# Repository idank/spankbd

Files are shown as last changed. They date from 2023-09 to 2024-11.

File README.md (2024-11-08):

# Span keyboard

span

Span is a low profile split keyboard with 3x5 column staggered keys with 2u, 1.5u, 1u thumb clusters.

The keyboard layout is derived from GergoPlex, a keyboard that was originally available on gboards.ca
(now defunct).

Features:

* 18x17 mm choc spacing.
* Optional 2u choc stabilizer.
* OLED support.
* Hybrid hotswap / direct soldering for switches.

The pcbs aren't reversible at the moment: I prefer the cleaner look of the top
side and generally think it's easier to deal with. A reversible version may be
added in the future.

## Availability

Kits and built keyboards can be purchased on *[holykeebs](https://holykeebs.com)*.

Gerber files are available in the releases page.

span bottom plate
span with an oled

## Guide

See this [page](https://docs.holykeebs.com/guides/keyboard/).

## License

This work is licensed under a
[Creative Commons Attribution-ShareAlike 4.0 International License][cc-by-sa].

[cc-by-sa]: http://creativecommons.org/licenses/by-sa/4.0/

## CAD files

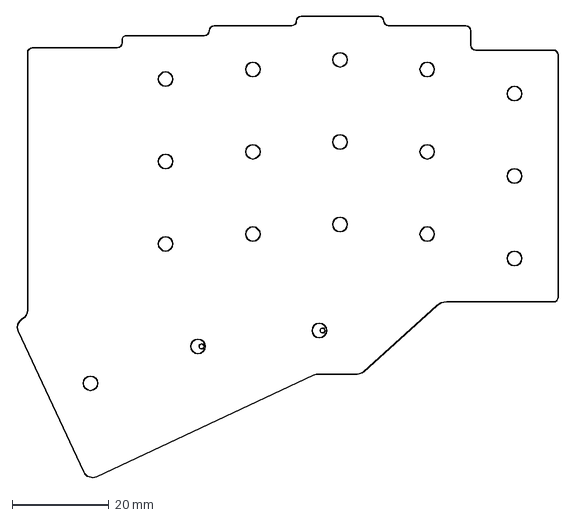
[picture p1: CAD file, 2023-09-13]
pcb/outline.dxf
111.9 x 95.3 mm

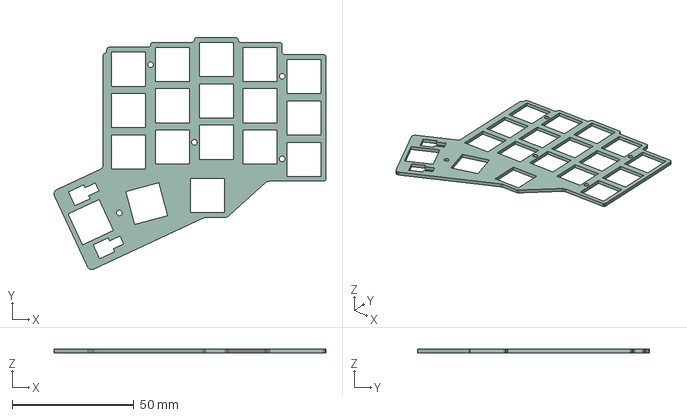
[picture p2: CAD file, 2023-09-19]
plate/span.step
111.6 x 95.2 x 1.58 mm

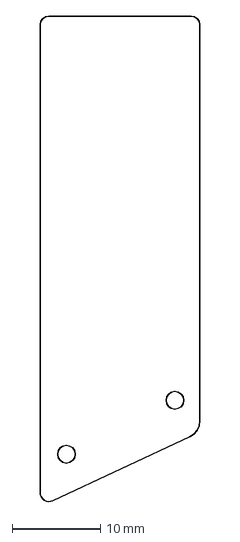
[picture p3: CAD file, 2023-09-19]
misc/oled.dxf
18.1 x 55.0 mm

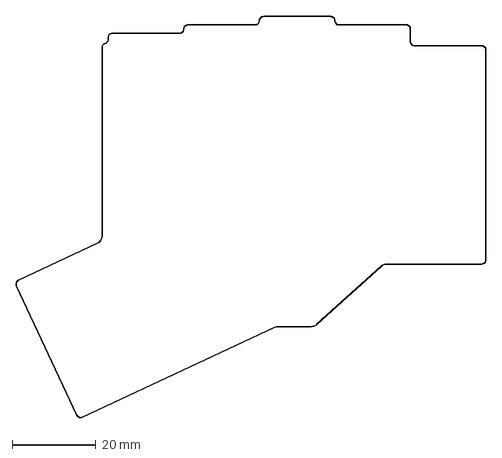
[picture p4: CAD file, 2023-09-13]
plate/plate.dxf
112.0 x 95.6 mm

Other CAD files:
misc/acrylic plate.dxf
plate/span plate.STEP

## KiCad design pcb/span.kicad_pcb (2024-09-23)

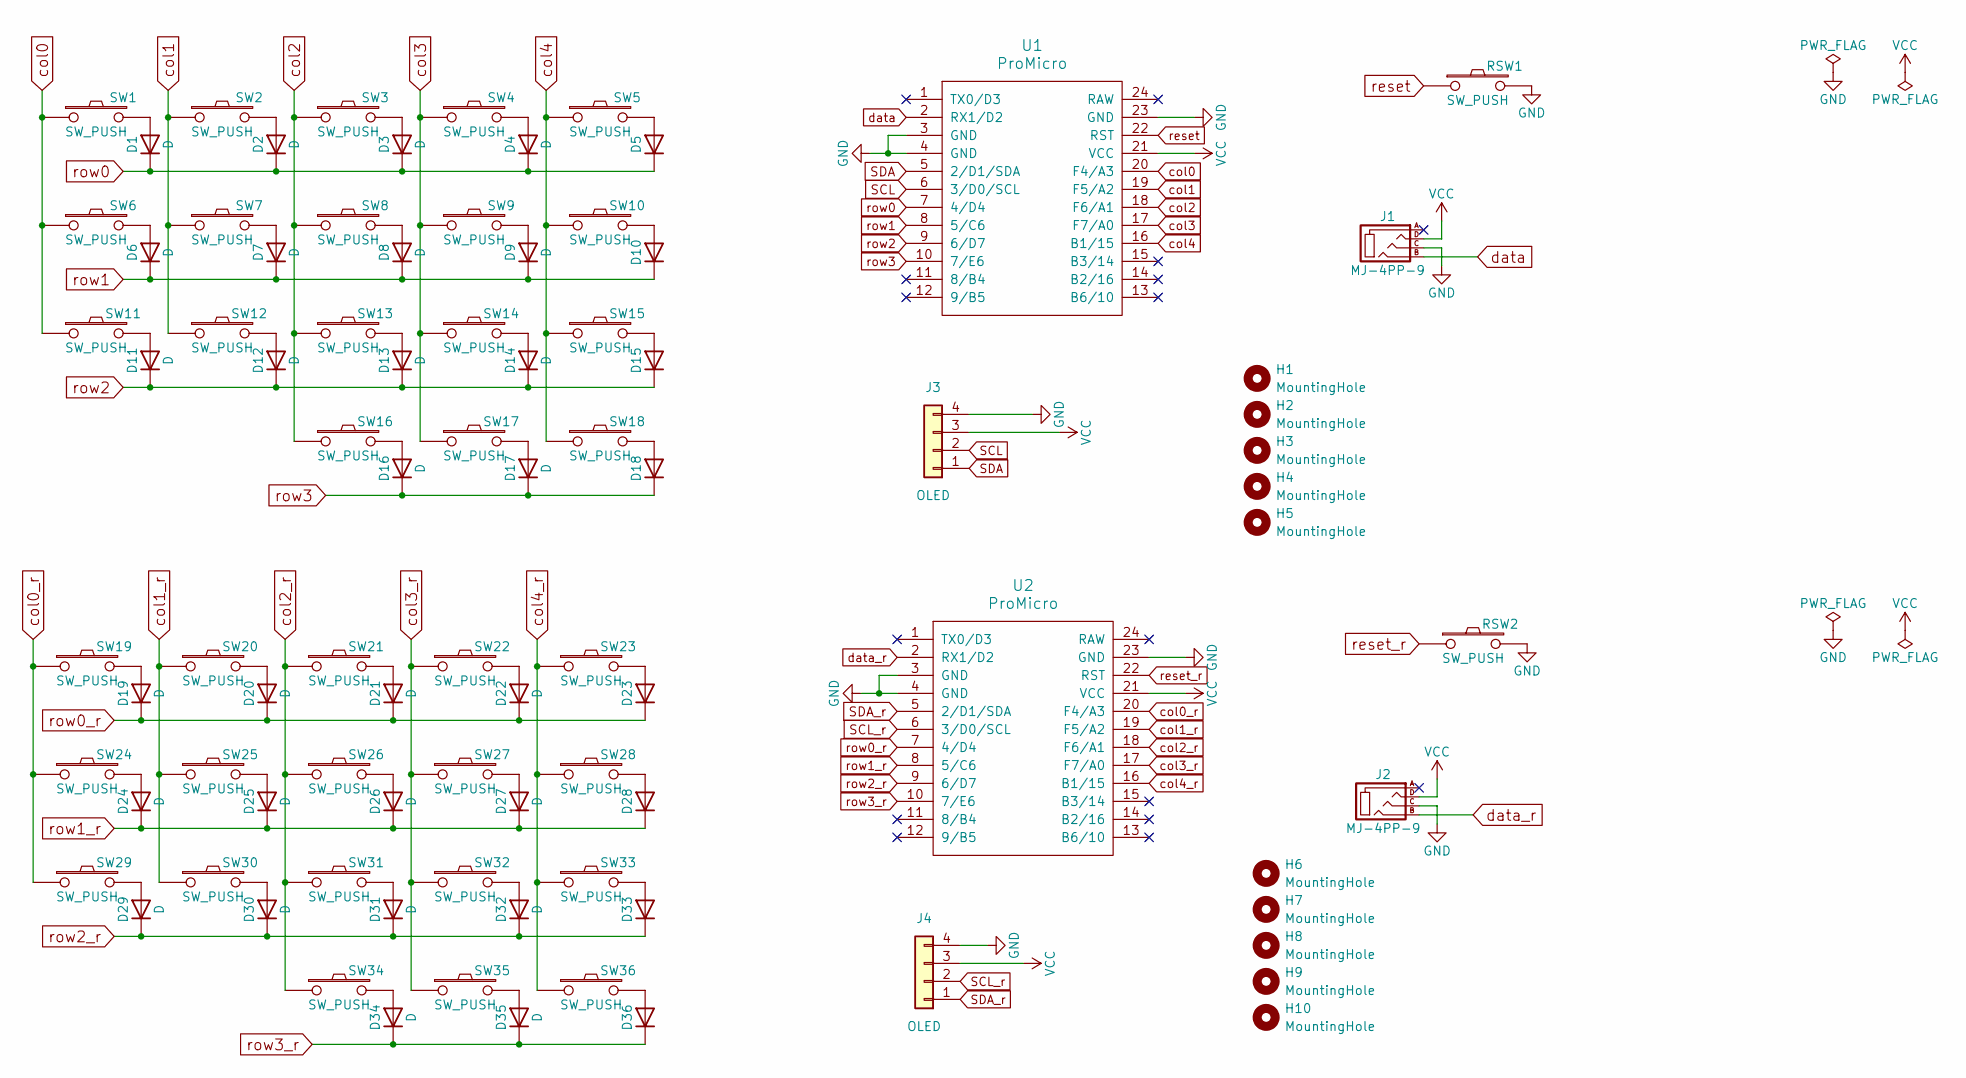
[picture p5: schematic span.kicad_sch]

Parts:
D1, D2, D3, D4, D5, D6, D7, D8, D9, D10, D11, D12, D13, D14, D15, D16, D17, D18, D19, D20, D21, D22, D23, D24, D25, D26, D27, D28, D29, D30, D31, D32, D33, D34, D35, D36: D; D3_SMD_v2
H1, H2, H3, H4, H5, H6, H7, H8, H9, H10: MountingHole; M2_SPACER
J1, J2: MJ-4PP-9; MJ-4PP-9_1side
J3, J4: OLED; OLED_1side
RSW1, RSW2: SW_PUSH; RSW_2PIN_SMD
SW1, SW2, SW3, SW4, SW5, SW6, SW7, SW8, SW9, SW10, SW11, SW12, SW13, SW14, SW15, SW16, SW17, SW19, SW20, SW21, SW22, SW23, SW24, SW25, SW26, SW27, SW28, SW29, SW30, SW31, SW32, SW33, SW34, SW35: SW_PUSH; Kailh_socket_PG1350_optional_oval_smaller_hotswap
SW18, SW36: SW_PUSH; Kailh_socket_PG1350_2u_optional_oval
U1, U2: ProMicro; ProMicro_1mm_holes

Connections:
GND: J1.C, J2.C, J3.4, J4.4, RSW1.2, RSW2.2, U1.3 (GND), U1.4 (GND), U1.23 (GND), U2.3 (GND), U2.4 (GND), U2.23 (GND)
unnamed: D1.2 (A), SW1.2
unnamed: D2.2 (A), SW2.2
unnamed: D3.2 (A), SW3.2
unnamed: D4.2 (A), SW4.2
unnamed: D5.2 (A), SW5.2
unnamed: D6.2 (A), SW6.2
unnamed: D7.2 (A), SW7.2
unnamed: D8.2 (A), SW8.2
unnamed: D9.2 (A), SW9.2
unnamed: D10.2 (A), SW10.2
unnamed: D11.2 (A), SW11.2
unnamed: D12.2 (A), SW12.2
unnamed: D13.2 (A), SW13.2
unnamed: D14.2 (A), SW14.2
unnamed: D15.2 (A), SW15.2
unnamed: D16.2 (A), SW16.2
unnamed: D17.2 (A), SW17.2
unnamed: D18.2 (A), SW18.2
unnamed: D19.2 (A), SW19.2
unnamed: D20.2 (A), SW20.2
unnamed: D21.2 (A), SW21.2
unnamed: D22.2 (A), SW22.2
unnamed: D23.2 (A), SW23.2
unnamed: D24.2 (A), SW24.2
unnamed: D25.2 (A), SW25.2
unnamed: D26.2 (A), SW26.2
unnamed: D27.2 (A), SW27.2
unnamed: D28.2 (A), SW28.2
unnamed: D29.2 (A), SW29.2
unnamed: D30.2 (A), SW30.2
unnamed: D31.2 (A), SW31.2
unnamed: D32.2 (A), SW32.2
unnamed: D33.2 (A), SW33.2
unnamed: D34.2 (A), SW34.2
unnamed: D35.2 (A), SW35.2
unnamed: D36.2 (A), SW36.2
SCL: J3.2, U1.6 (3/D0/SCL)
SCL_r: J4.2, U2.6 (3/D0/SCL)
SDA: J3.1, U1.5 (2/D1/SDA)
SDA_r: J4.1, U2.5 (2/D1/SDA)
VCC: J1.D, J2.D, J3.3, J4.3, U1.21 (VCC), U2.21 (VCC)
col0: SW1.1, SW6.1, SW11.1, U1.20 (F4/A3)
col0_r: SW19.1, SW24.1, SW29.1, U2.20 (F4/A3)
col1: SW2.1, SW7.1, SW12.1, U1.19 (F5/A2)
col1_r: SW20.1, SW25.1, SW30.1, U2.19 (F5/A2)
col2: SW3.1, SW8.1, SW13.1, SW16.1, U1.18 (F6/A1)
col2_r: SW21.1, SW26.1, SW31.1, SW34.1, U2.18 (F6/A1)
col3: SW4.1, SW9.1, SW14.1, SW17.1, U1.17 (F7/A0)
col3_r: SW22.1, SW27.1, SW32.1, SW35.1, U2.17 (F7/A0)
col4: SW5.1, SW10.1, SW15.1, SW18.1, U1.16 (B1/15)
col4_r: SW23.1, SW28.1, SW33.1, SW36.1, U2.16 (B1/15)
data: J1.B, U1.2 (RX1/D2)
data_r: J2.B, U2.2 (RX1/D2)
reset: RSW1.1, U1.22 (RST)
reset_r: RSW2.1, U2.22 (RST)
row0: D1.1 (K), D2.1 (K), D3.1 (K), D4.1 (K), D5.1 (K), U1.7 (4/D4)
row0_r: D19.1 (K), D20.1 (K), D21.1 (K), D22.1 (K), D23.1 (K), U2.7 (4/D4)
row1: D6.1 (K), D7.1 (K), D8.1 (K), D9.1 (K), D10.1 (K), U1.8 (5/C6)
row1_r: D24.1 (K), D25.1 (K), D26.1 (K), D27.1 (K), D28.1 (K), U2.8 (5/C6)
row2: D11.1 (K), D12.1 (K), D13.1 (K), D14.1 (K), D15.1 (K), U1.9 (6/D7)
row2_r: D29.1 (K), D30.1 (K), D31.1 (K), D32.1 (K), D33.1 (K), U2.9 (6/D7)
row3: D16.1 (K), D17.1 (K), D18.1 (K), U1.10 (7/E6)
row3_r: D34.1 (K), D35.1 (K), D36.1 (K), U2.10 (7/E6)

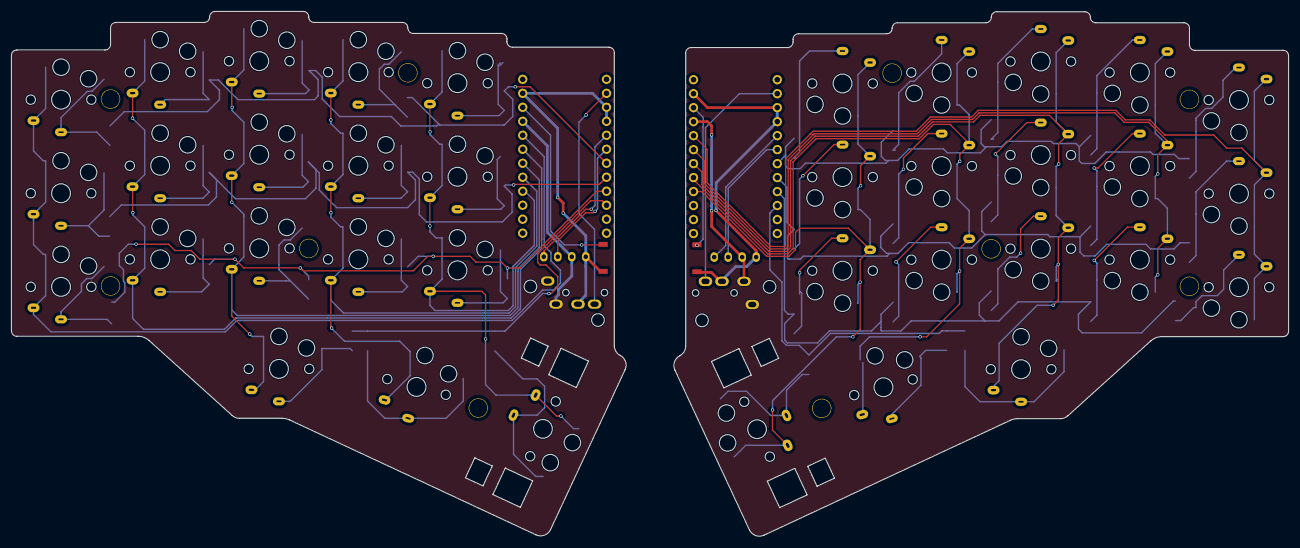
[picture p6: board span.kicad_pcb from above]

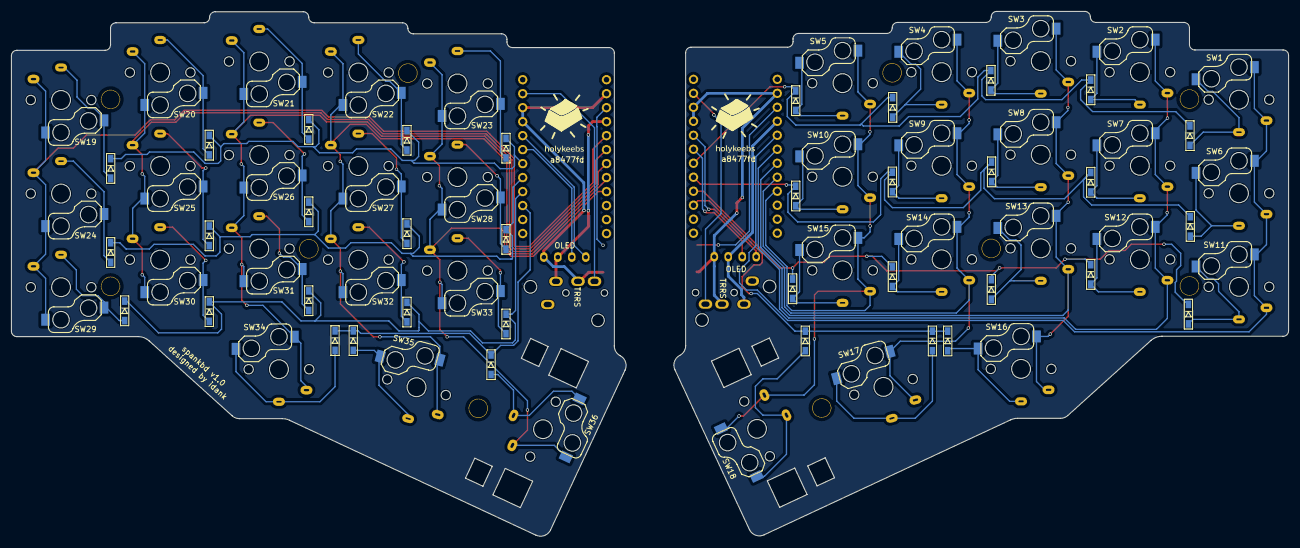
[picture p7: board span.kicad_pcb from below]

Board: 2 copper layers, 232.0 x 95.3 mm, 90 parts (41 on the bottom side), 64 nets.

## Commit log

2023-09-13 pcb: bump version
    [span.kicad_pcb]
2023-09-14 readme: add note regarding gerber files
2023-09-14 pcb: ungroup left / right mounting holes
    [span.kicad_pcb]
2023-09-19 misc: add acrylic plate, oled dxf files
    [acrylic plate.dxf, oled.dxf, span plate.STEP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]
2024-01-23 pcb: enlarge m2 holes to 3.2 mm to allow a bit more slop
    [span.kicad_pcb]
2024-01-23 pcb: add holykeebs logo, fix attribution
    [span.kicad_pcb]
2024-02-13 pcb: use slightly bigger holes for the controller pins and mounting holes
    [span.kicad_pcb, span.kicad_sch]
2024-09-23 pcb: add filled zones
    [span.kicad_pcb, span.kicad_sch]
